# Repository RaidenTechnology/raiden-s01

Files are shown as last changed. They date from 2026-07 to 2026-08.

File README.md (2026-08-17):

# Raiden S0-1

**Open-hardware ESP32-S3 development board — designed from scratch in KiCad 9.**

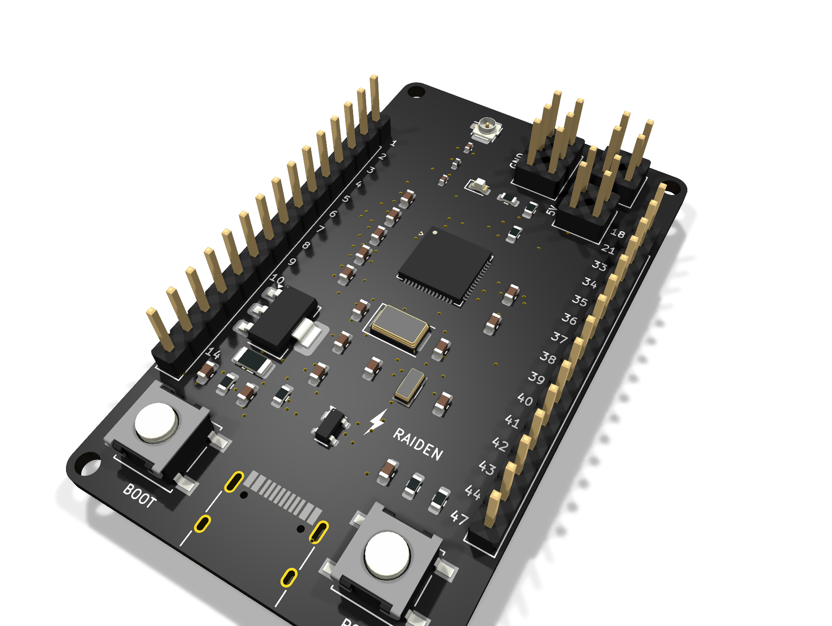
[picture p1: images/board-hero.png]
Raiden S0-1


## Overview

The Raiden S0-1 is a compact 4-layer devkit built around the **ESP32-S3FN8** (dual-core Xtensa LX7 @ 240 MHz, Wi-Fi + BLE 5, 8 MB embedded flash). Designed, routed and verified entirely by [Raiden Technology](https://github.com/RaidenTechnology).

| | |
|---|---|
| **MCU** | ESP32-S3FN8 (QFN-56, 8 MB flash) |
| **USB** | USB-C (USB 2.0), ESD-protected (PRTR5V0U2X), 5.1 kΩ CC pull-downs |
| **Power** | AZ1117C-3.3 LDO, 750 mA PTC resettable fuse, power LED |
| **RF** | U.FL (IPEX) antenna connector, feed line drawn for 50 Ω single-ended with a pi matching network — see the note below, impedance is **not** verified |
| **Clocks** | 40 MHz main crystal (CL = 8 pF) · 32.768 kHz RTC crystal (CL = 12.5 pF) |
| **I/O** | 2 × 15-pin 2.54 mm headers, BOOT + RESET buttons |
| **Board** | 4-layer FR-4, 1.6 mm — Sig / GND / +3V3 / Sig stackup, black soldermask |
| **Mounting** | 4 × M2 holes (NPTH) |

## Board views

| Top | Bottom |
|---|---|
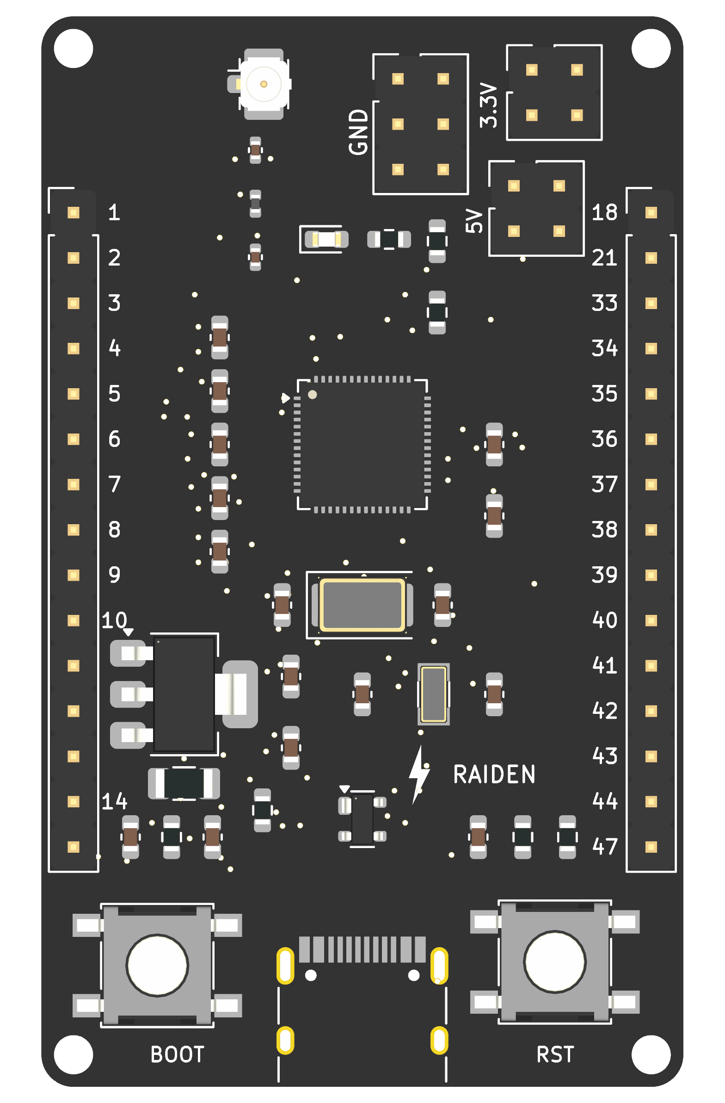
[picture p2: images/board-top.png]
Top
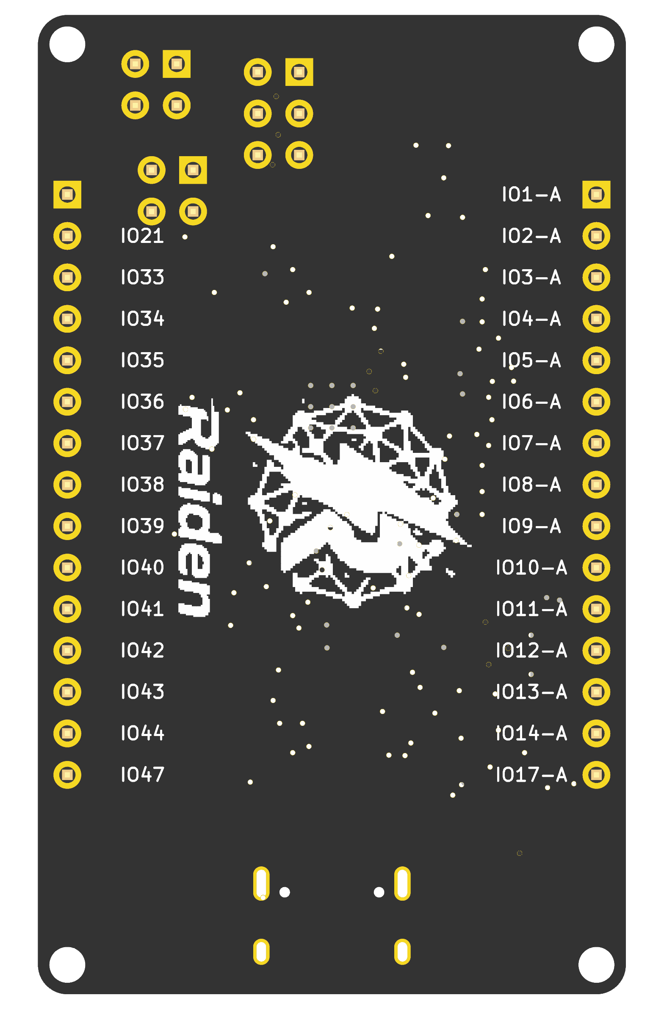
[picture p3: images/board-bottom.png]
Bottom
|  |  |

## Verification

- **ERC: 0 errors** — **DRC: 0 errors, 0 unconnected items** (KiCad 9.0.7, `kicad-cli`)
- 5 permanent DRC notices are intentional local footprint overrides (U.FL RF keepout + M2 mounting holes)

### Known limitations

- **The RF feed is not impedance-verified.** The trace is drawn at 0.2 mm and the design intent is 50 Ω single-ended, but no controlled-impedance stackup was ever defined for the project, so 50 Ω is an assumption rather than a calculated or measured figure. The pi matching network (1 pF / 2.0 nH / 1 pF) uses starting values with no VNA behind them and is expected to be tuned after measurement.
- **The board has not been manufactured.** The design is complete and the fabrication package is generated, but no production run has happened, so nothing here has been validated on real silicon.

## Repository layout

```
hardware/   KiCad 9 project (schematic, PCB, project file)
fab/        Production package: Gerbers (4-layer), drill files,
            BOM + CPL (JLCPCB format), pick-and-place, schematic PDF
images/     kicad-cli 3D renders
```

## Fabrication notes

Full notes in [`fab/README.txt`](fab/README.txt). Highlights:

- Standard 4-layer stackup (JLC7628 or equivalent)
- RF feed line routed for 50 Ω single-ended — ask your fab to adjust trace width to their stackup
- Via-in-pad under the SOT-223 regulator tab: plugged (IPC-4761 Type VI) or at least tented
- QFN-56 (0.4 mm pitch) — stencil and reflow profile matter
- Crystal load capacitance is board-matched: use CL = 8 pF for the 40 MHz crystal (C9/C10 = 10 pF)

## Status

Rev A — design complete and verification-clean; first fabrication run pending.

## License

Hardware licensed under **CERN-OHL-P v2** ([LICENSE](LICENSE)). Use it, modify it, build on it.

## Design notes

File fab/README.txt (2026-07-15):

RAIDEN S0-1 — ESP32-S3FN8 DEVKIT — Rev A — 2026-07-14
Raiden Technology
========================================================

ICERIK / CONTENTS
  Gerber\                        Gerber (11 katman) + Excellon delik (.drl) + delik haritasi
  Raiden S0-1 BOM.csv            Malzeme listesi (MPN'li, Value+MPN gruplu)
  Raiden S0-1 PickAndPlace.csv   Dizgi koordinat dosyasi (mm, ust+alt)
  Raiden S0-1 Schematic.pdf      Sema

URETIM NOTLARI / FABRICATION NOTES
  1. 4 katman / 4-layer, 1.6 mm FR-4.
     Stackup: F.Cu (sinyal) / In1.Cu = GND duzlemi / In2.Cu = +3.3V duzlemi / B.Cu (sinyal)
     JLC7628 veya esdegeri standart stackup uygundur.
  2. Soldermask: SIYAH / BLACK. Silkscreen: BEYAZ / WHITE (her iki yuz).
  3. KONTROLLU EMPEDANS / CONTROLLED IMPEDANCE:
     RF hatti LNA_IN -> ANT1 (F.Cu, 0.2 mm, kart ust bolgesi x~112) 50 ohm single-ended.
     Fab stackup'ina gore iz genisligi fab tarafindan ayarlanabilir / please adjust
     trace width to 50 ohm per your stackup, or advise required width.
  4. VIA-IN-PAD: U2 (SOT-223 regulator) tab pad'i altinda via (111.15, 138.75).
     Lutfen kapatin / plugged (IPC-4761 Type VI) veya en az tented.
  5. H1-H4: 4x M2 montaj deligi, NPTH (kaplamasiz) / non-plated.
  6. Min iz/bosluk / min track/clearance: 0.2 mm / 0.2 mm. Min delik / min drill: 0.3 mm.

DIZGI NOTLARI / ASSEMBLY NOTES
  - U1 = QFN-56 0.4 mm pitch, EP 4x4 mm — stencil ve refill profili onemli.
  - Y2 40 MHz kristal MUTLAKA CL = 8 pF olmali (C9/C10 = 10 pF buna gore secildi).
    Onerilen / suggested: ECS-400-8-30B-CKM.
  - Y1 32.768 kHz kristal CL = 12.5 pF (Epson FC-135; C11/C12 = 22 pF).
  - BOM'daki MPN'ler oneridir; stok/fiyat siparis oncesi dogrulanmali.

DOGRULAMA / VERIFICATION (KiCad 9.0.7, kicad-cli)
  ERC: 0 hata. DRC: 0 hata, 0 kopuk baglanti.
  (5 kalici uyari = kasitli yerel footprint kopyalari: ANT1 RF keepout + H1-H4.)

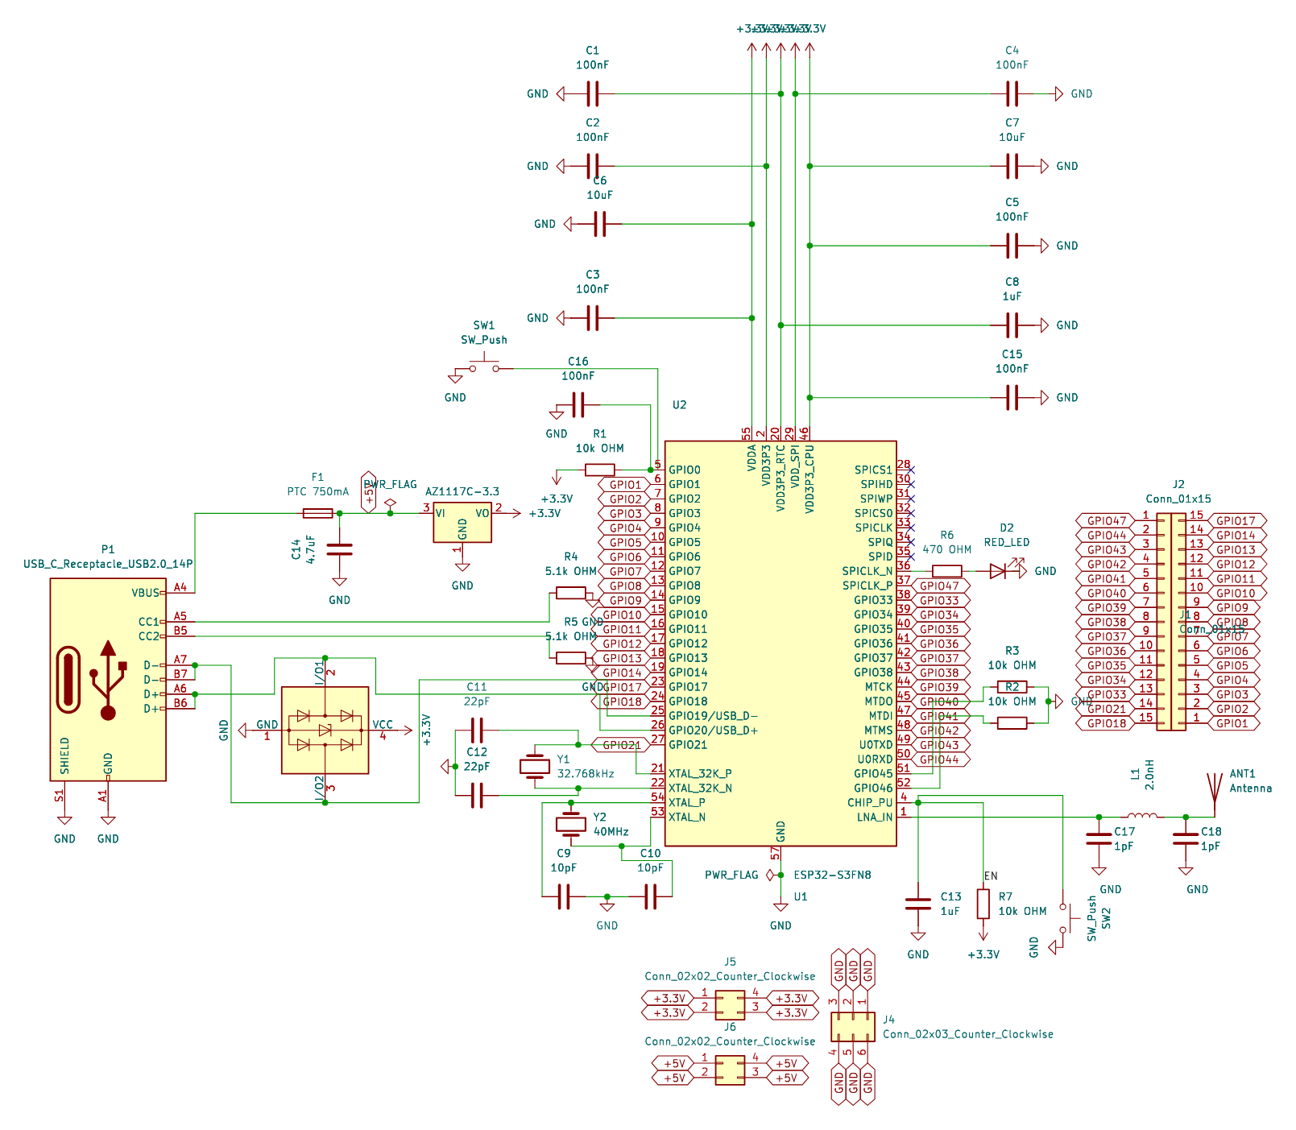
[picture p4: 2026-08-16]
images/schematic.png

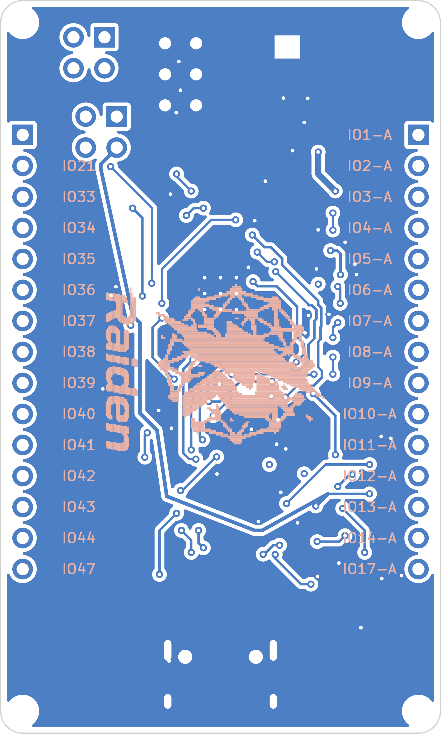
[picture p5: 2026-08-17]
images/pcb-back.png

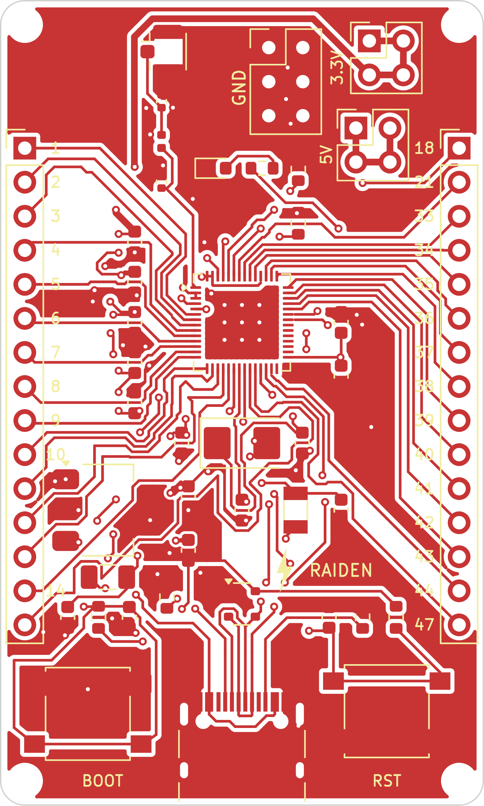
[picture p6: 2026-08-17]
images/pcb-front.png

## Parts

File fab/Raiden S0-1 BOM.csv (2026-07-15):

Reference | Value | MPN | Footprint
ANT1 | Antenna | U.FL-R-SMT-1(10) | Connector_Coaxial:U.FL_Hirose_U.FL-R-SMT-1_Vertical
C1-C5,C15,C16 | 100nF | CL10B104KB8NNNC | Capacitor_SMD:C_0603_1608Metric
C6,C7 | 10uF | CL10A106KP8NNNC | Capacitor_SMD:C_0603_1608Metric
C8,C13 | 1uF | CL10A105KB8NNNC | Capacitor_SMD:C_0603_1608Metric
C9,C10 | 10pF | CL10C100JB8NNNC | Capacitor_SMD:C_0603_1608Metric
C11,C12 | 22pF | CL10C220JB8NNNC | Capacitor_SMD:C_0603_1608Metric
C14 | 4.7uF | CL10A475KP8NNNC | Capacitor_SMD:C_0603_1608Metric
C17,C18 | 1pF | CL05C010BB5NNNC | Capacitor_SMD:C_0402_1005Metric
D1 | PRTR5V0U2X | PRTR5V0U2X,215 | Package_TO_SOT_SMD:SOT-143
D2 | RED_LED | KT-0603R | LED_SMD:LED_0603_1608Metric
F1 | PTC 750mA | 1206L075YR | Fuse:Fuse_1206_3216Metric
J1,J2 | Conn_01x15 |  | Connector_PinHeader_2.54mm:PinHeader_1x15_P2.54mm_Vertical
J4 | Conn_02x03_Counter_Clockwise |  | Connector_PinHeader_2.54mm:PinHeader_2x03_P2.54mm_Vertical
J5,J6 | Conn_02x02_Counter_Clockwise |  | Connector_PinHeader_2.54mm:PinHeader_2x02_P2.54mm_Vertical
L1 | 2.0nH | LQG15HS2N0S02D | Inductor_SMD:L_0402_1005Metric
P1 | USB_C_Receptacle_USB2.0_14P | TYPE-C-31-M-12 | Connector_USB:USB_C_Receptacle_HRO_TYPE-C-31-M-12
R1-R3,R7 | 10k OHM | 0603WAF1002T5E | Resistor_SMD:R_0603_1608Metric
R4,R5 | 5.1k OHM | 0603WAF5101T5E | Resistor_SMD:R_0603_1608Metric
R6 | 470 OHM | 0603WAF4700T5E | Resistor_SMD:R_0603_1608Metric
SW1,SW2 | SW_Push | B3S-1000 | Button_Switch_SMD:SW_SPST_B3S-1000
U1 | ESP32-S3FN8 | ESP32-S3FN8 | Package_DFN_QFN:QFN-56-1EP_7x7mm_P0.4mm_EP4x4mm
U2 | AZ1117C-3.3 | AZ1117CH-3.3TRG1 | Package_TO_SOT_SMD:SOT-223
Y1 | 32.768kHz | Q13FC1350000400 | Crystal:Crystal_SMD_3215-2Pin_3.2x1.5mm
Y2 | 40MHz | ECS-400-8-30B-CKM | Crystal:Crystal_SMD_5032-2Pin_5.0x3.2mm

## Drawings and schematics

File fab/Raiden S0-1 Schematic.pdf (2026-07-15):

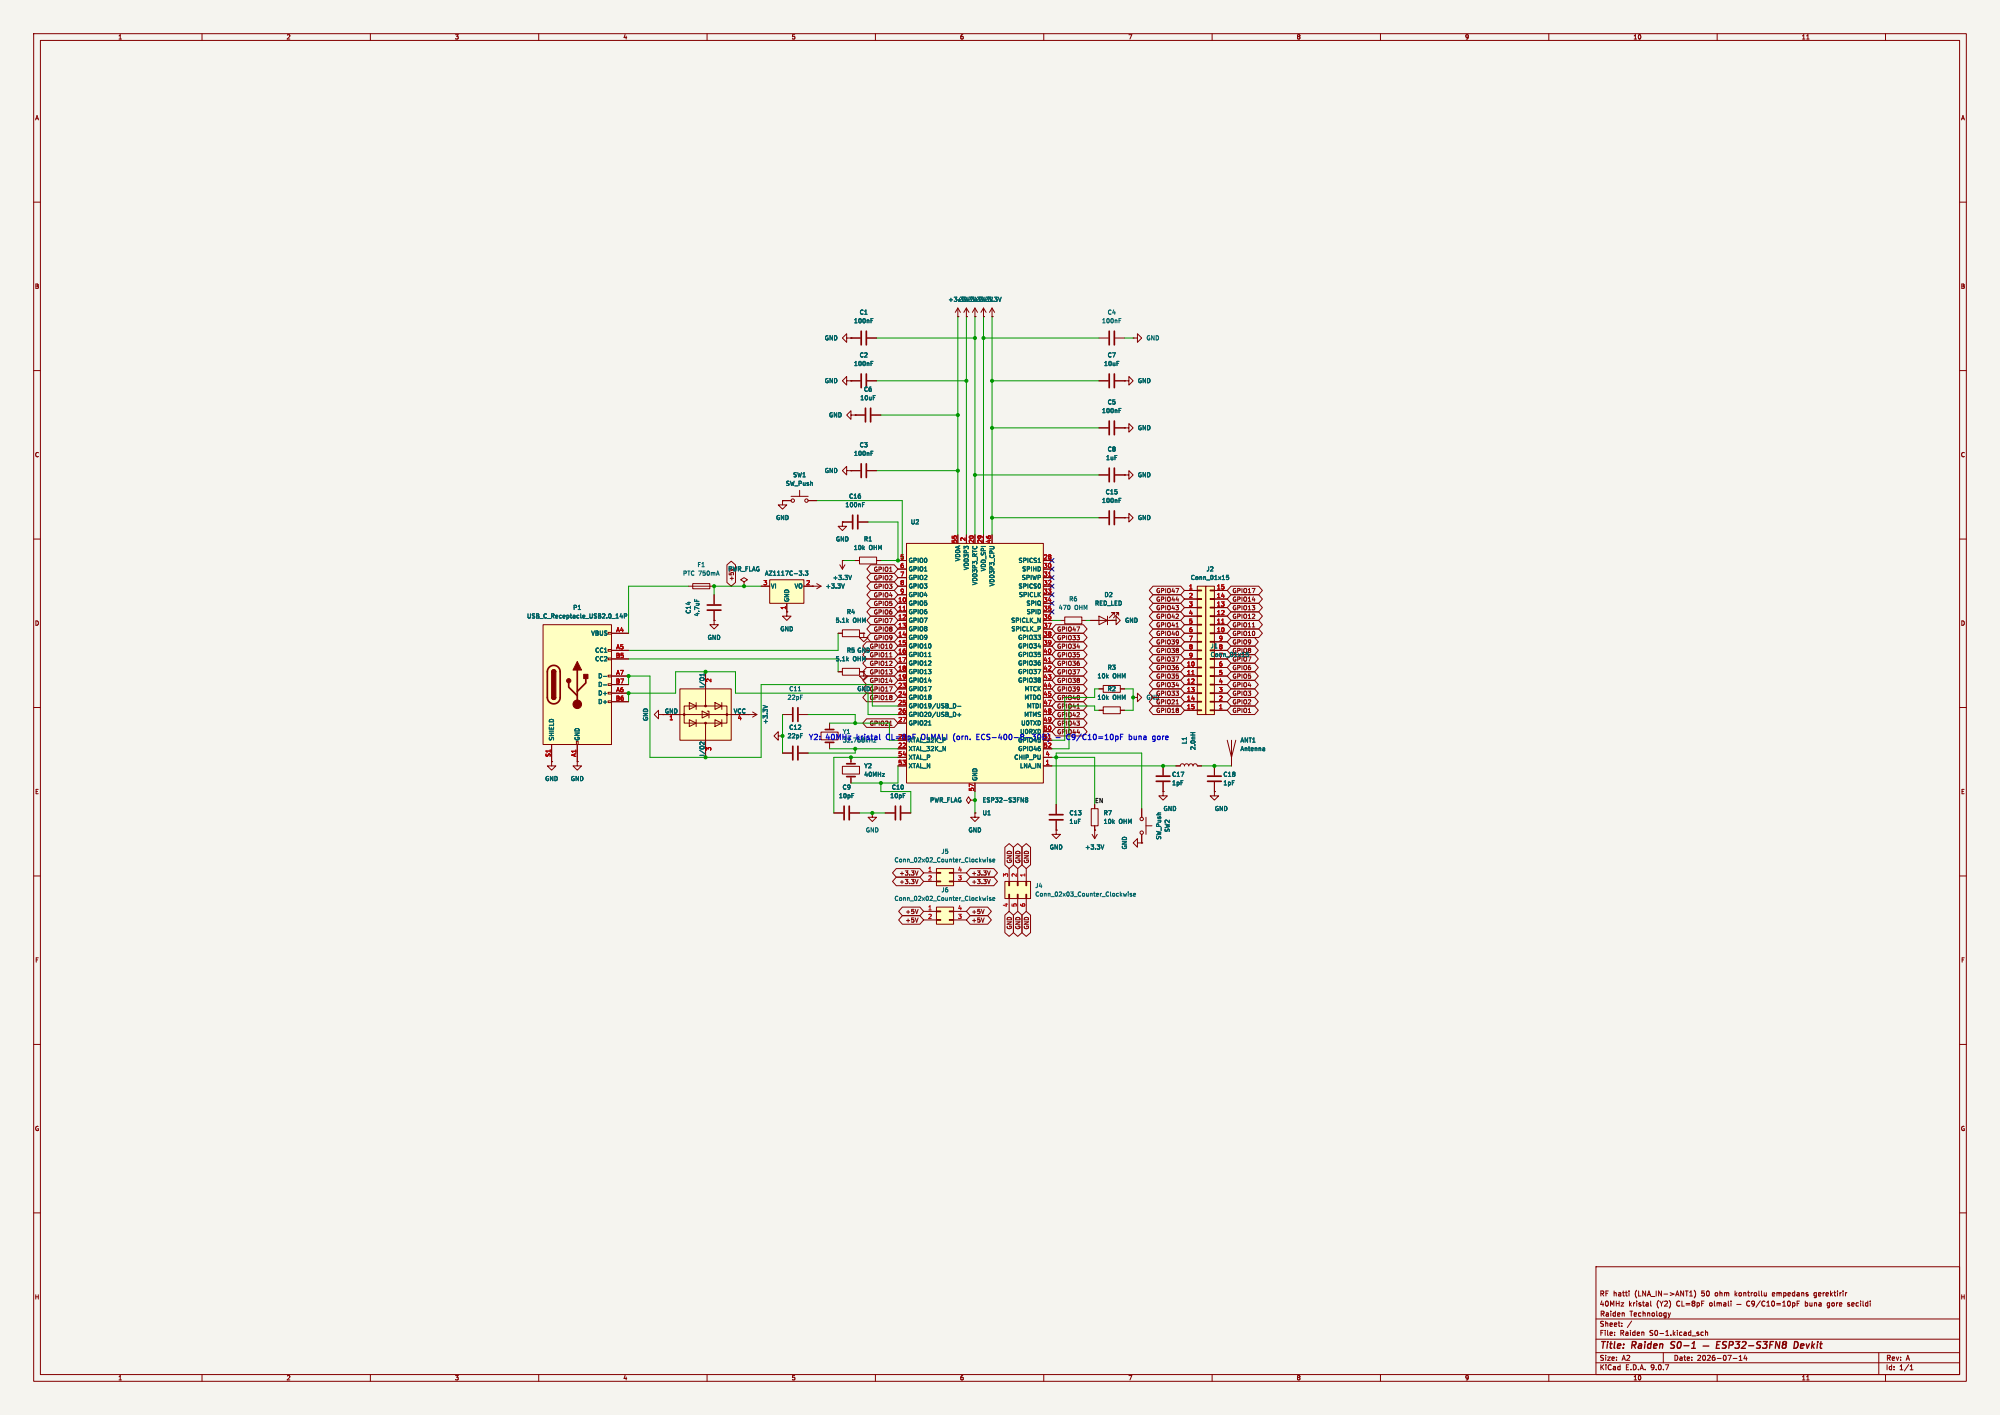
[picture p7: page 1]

2 VDD3P3_RTC 20 GND 57 VDD_SPI 29 VDD3P3_CPU 46 SPICS1 28 SPIHD 30 SPIWP 31 SPICS0 32 SPICLK 33 SPIQ 34 SPID 35 SPICLK_P 37 GPIO33 38 GPIO34 39 GPIO35 40 GPIO36 41 GPIO37 42 GPIO38 43 MTCK 44 MTDI 47 MTMS 48 U0TXD 49 U0RXD 50 GPIO46 52 CHIP_PU 4

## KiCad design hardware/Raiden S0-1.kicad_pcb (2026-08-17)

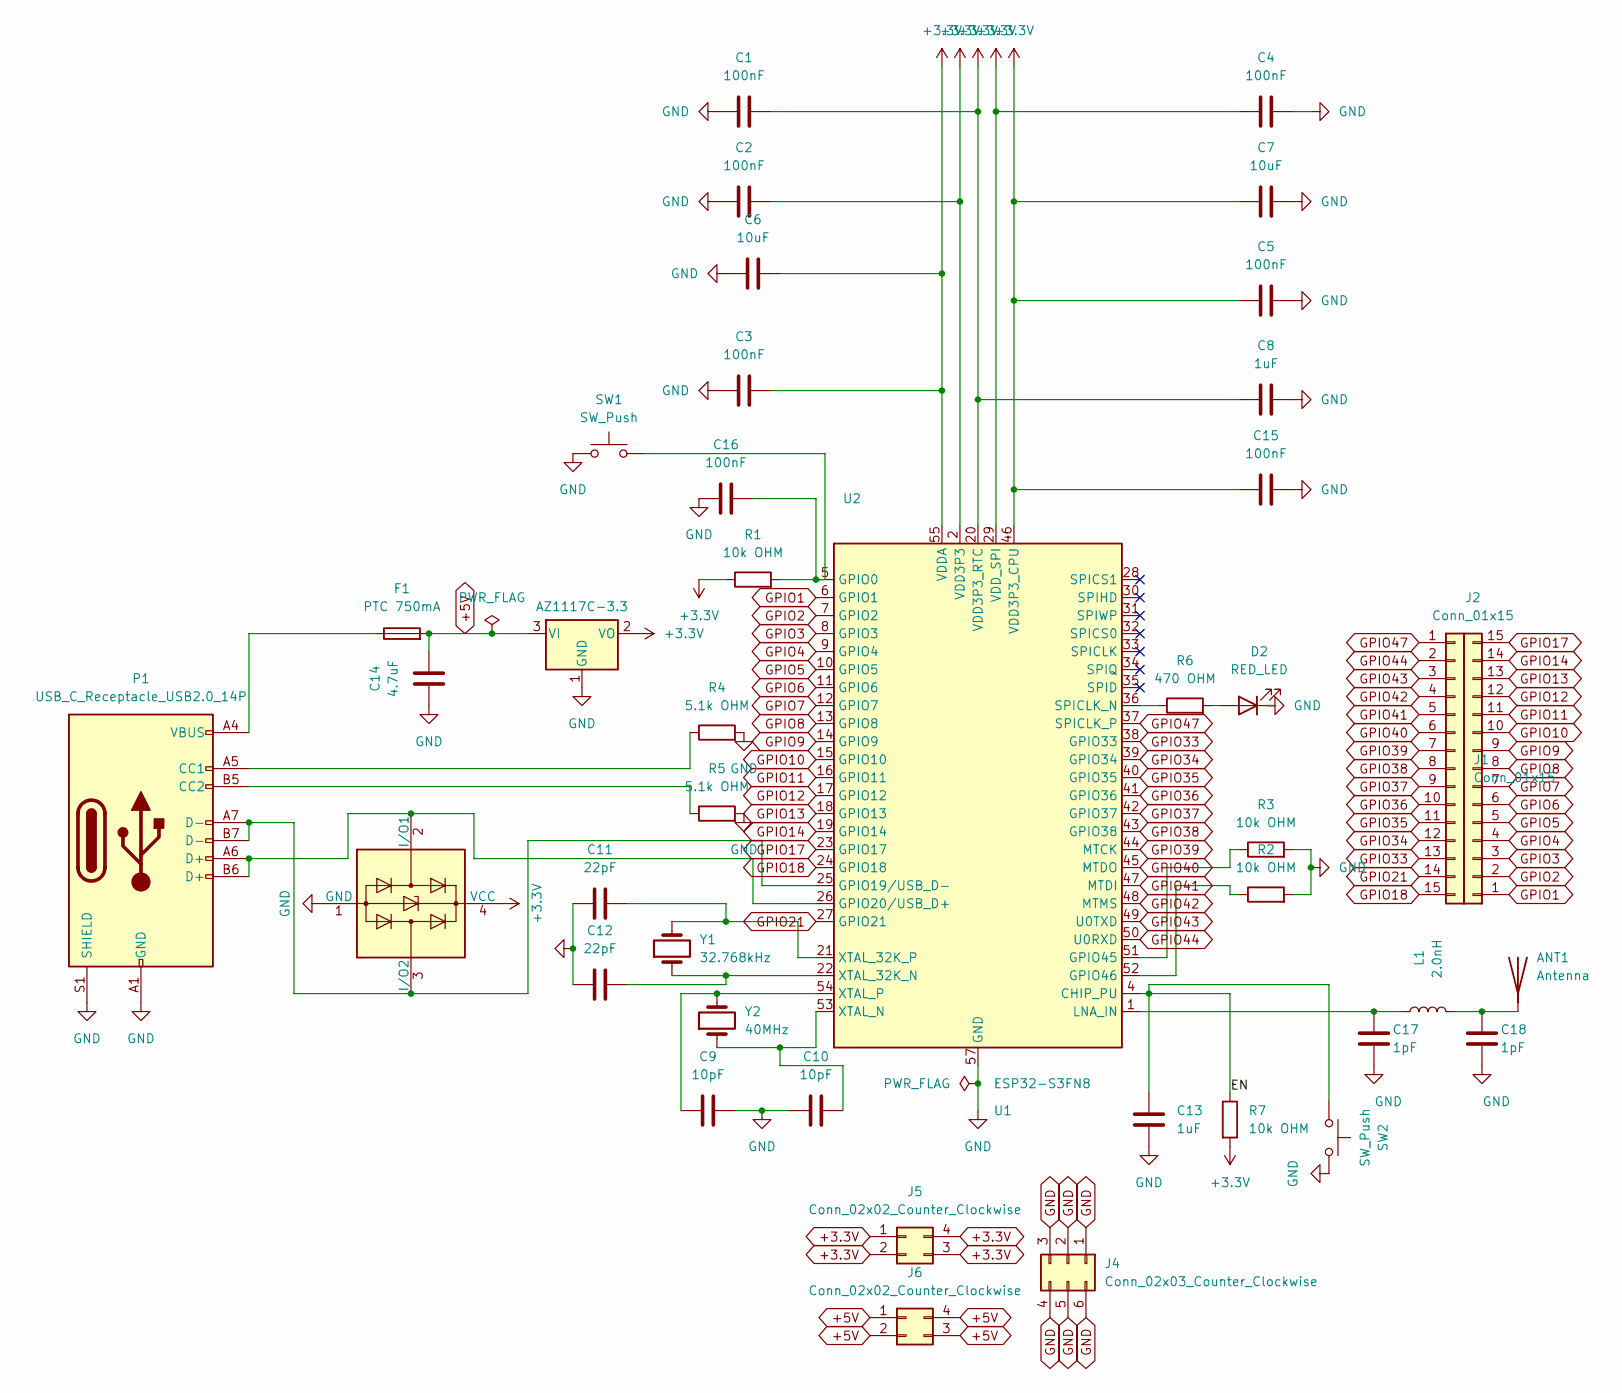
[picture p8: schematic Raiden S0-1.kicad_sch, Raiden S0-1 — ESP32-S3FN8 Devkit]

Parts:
ANT1: Antenna; U.FL_Hirose_U.FL-R-SMT-1_Vertical; MPN U.FL-R-SMT-1(10)
C1, C2, C3, C4, C5, C15, C16: 100nF; C_0603_1608Metric; MPN CL10B104KB8NNNC
C6, C7: 10uF; C_0603_1608Metric; MPN CL10A106KP8NNNC
C8, C13: 1uF; C_0603_1608Metric; MPN CL10A105KB8NNNC
C9, C10: 10pF; C_0603_1608Metric; MPN CL10C100JB8NNNC
C11, C12: 22pF; C_0603_1608Metric; MPN CL10C220JB8NNNC
C14: 4.7uF; C_0603_1608Metric; MPN CL10A475KP8NNNC
C17, C18: 1pF; C_0402_1005Metric; MPN CL05C010BB5NNNC
D1: PRTR5V0U2X; SOT-143; MPN PRTR5V0U2X,215
D2: RED_LED; LED_0603_1608Metric; MPN KT-0603R
F1: PTC 750mA; Fuse_1206_3216Metric; MPN 1206L075YR
J1, J2: Conn_01x15; PinHeader_1x15_P2.54mm_Vertical
J4: Conn_02x03_Counter_Clockwise; PinHeader_2x03_P2.54mm_Vertical
J5, J6: Conn_02x02_Counter_Clockwise; PinHeader_2x02_P2.54mm_Vertical
L1: 2.0nH; L_0402_1005Metric; MPN LQG15HS2N0S02D
P1: USB_C_Receptacle_USB2.0_14P; USB_C_Receptacle_HRO_TYPE-C-31-M-12; MPN TYPE-C-31-M-12
R1, R2, R3, R7: 10k OHM; R_0603_1608Metric; MPN 0603WAF1002T5E
R4, R5: 5.1k OHM; R_0603_1608Metric; MPN 0603WAF5101T5E
R6: 470 OHM; R_0603_1608Metric; MPN 0603WAF4700T5E
SW1, SW2: SW_Push; SW_SPST_B3S-1000; MPN B3S-1000
U1: ESP32-S3FN8; QFN-56-1EP_7x7mm_P0.4mm_EP4x4mm; MPN ESP32-S3FN8
U2: AZ1117C-3.3; SOT-223; MPN AZ1117CH-3.3TRG1
Y1: 32.768kHz; Crystal_SMD_3215-2Pin_3.2x1.5mm; MPN Q13FC1350000400
Y2: 40MHz; Crystal_SMD_5032-2Pin_5.0x3.2mm; MPN ECS-400-8-30B-CKM

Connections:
+3.3V: C1.2, C2.2, C3.2, C4.1, C5.1, C6.2, C7.1, C8.1, C15.1, D1.4 (VCC), J5.1, J5.2, J5.3, J5.4, R1.1, R7.2, U1.2 (VDD3P3), U1.3 (VDD3P3), U1.20 (VDD3P3_RTC), U1.29 (VDD_SPI), U1.46 (VDD3P3_CPU), U1.55 (VDDA), U1.56 (VDDA), U2.2 (VO), U2.4
+5V: C14.2, F1.2, J6.1, J6.2, J6.3, J6.4, U2.3 (VI)
/EN: C13.1, R7.1, SW2.1, U1.4 (CHIP_PU)
GND: ANT1.2, C1.1, C2.1, C3.1, C4.2, C5.2, C6.1, C7.2, C8.2, C9.1, C10.1, C11.1, C12.1, C13.2, C14.1, C15.2, C16.1, C17.2, C18.2, D1.1 (GND), D2.1 (K), J4.1, J4.2, J4.3, J4.4, J4.5, J4.6, P1.A1 (GND), P1.A12 (GND), P1.B1 (GND), P1.B12 (GND), P1.S1 (SHIELD), R2.2, R3.2, R4.2, R5.2, SW1.1, SW2.2, U1.57 (GND), U2.1 (GND)
GPIO1: J2.1, U1.6 (GPIO1)
GPIO2: J2.2, U1.7 (GPIO2)
GPIO3: J2.3, U1.8 (GPIO3)
GPIO4: J2.4, U1.9 (GPIO4)
GPIO5: J2.5, U1.10 (GPIO5)
GPIO6: J2.6, U1.11 (GPIO6)
GPIO7: J2.7, U1.12 (GPIO7)
GPIO8: J2.8, U1.13 (GPIO8)
GPIO9: J2.9, U1.14 (GPIO9)
GPIO10: J2.10, U1.15 (GPIO10)
GPIO11: J2.11, U1.16 (GPIO11)
GPIO12: J2.12, U1.17 (GPIO12)
GPIO13: J2.13, U1.18 (GPIO13)
GPIO14: J2.14, U1.19 (GPIO14)
GPIO17: J2.15, U1.23 (GPIO17)
GPIO18: J1.15, U1.24 (GPIO18)
GPIO21: J1.14, U1.27 (GPIO21)
GPIO33: J1.13, U1.38 (GPIO33)
GPIO34: J1.12, U1.39 (GPIO34)
GPIO35: J1.11, U1.40 (GPIO35)
GPIO36: J1.10, U1.41 (GPIO36)
GPIO37: J1.9, U1.42 (GPIO37)
GPIO38: J1.8, U1.43 (GPIO38)
GPIO39: J1.7, U1.44 (MTCK)
GPIO40: J1.6, U1.45 (MTDO)
GPIO41: J1.5, U1.47 (MTDI)
GPIO42: J1.4, U1.48 (MTMS)
GPIO43: J1.3, U1.49 (U0TXD)
GPIO44: J1.2, U1.50 (U0RXD)
GPIO47: J1.1, U1.37 (SPICLK_P)
unnamed: ANT1.1, C18.1, L1.2
unnamed: D1.2 (I/O1), P1.A6 (D+), P1.B6 (D+), U1.26 (GPIO20/USB_D+)
unnamed: D1.3 (I/O2), P1.A7 (D-), P1.B7 (D-), U1.25 (GPIO19/USB_D-)
unnamed: D2.2 (A), R6.2
unnamed: F1.1, P1.A4 (VBUS), P1.A9 (VBUS), P1.B4 (VBUS), P1.B9 (VBUS)
unnamed: P1.A5 (CC1), R4.1
unnamed: P1.B5 (CC2), R5.1
unnamed: C16.2, R1.2, SW1.2, U1.5 (GPIO0)
unnamed: R3.1, U1.51 (GPIO45)
unnamed: R2.1, U1.52 (GPIO46)
unnamed: C17.1, L1.1, U1.1 (LNA_IN)
unnamed: R6.1, U1.36 (SPICLK_N)
unnamed: C12.2, U1.22 (XTAL_32K_N), Y1.1
unnamed: C11.2, U1.21 (XTAL_32K_P), Y1.2
unnamed: C10.2, U1.53 (XTAL_N), Y2.1
unnamed: C9.2, U1.54 (XTAL_P), Y2.2

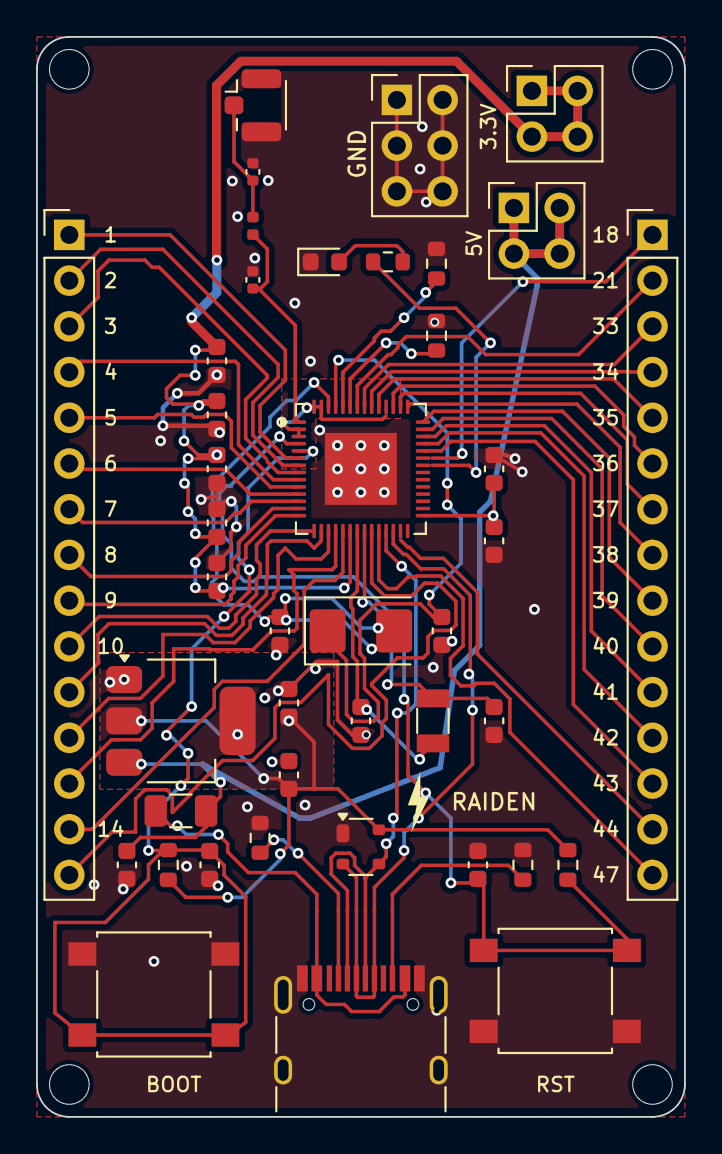
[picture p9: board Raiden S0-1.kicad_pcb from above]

Board: 4 copper layers, 36.0 x 60.0 mm, 46 parts (0 on the bottom side), 50 nets.

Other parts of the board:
H1, H2, H3, H4: MountingHole_M2; MountingHole_2.2mm_M2

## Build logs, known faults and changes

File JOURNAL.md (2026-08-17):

# Raiden S0-1 — Build Journal

**Project:** an open-hardware ESP32-S3 development board, designed from scratch in KiCad 9.
**Author:** Raiden Technology
**Repo:** https://github.com/RaidenTechnology/raiden-s01
**License:** CERN-OHL-P v2
**Total time:** ~60 hours across six sessions, 11–15 July 2026

> **A note on this journal, up front:** the design work happened over 11–15 July 2026. I
> published the repository as a single release commit on 15 July and only wrote this journal
> afterwards, from my own working notes. So the entries below are an honest reconstruction of
> real sessions, not a live log — I'd rather say that than pretend the commit history shows
> something it doesn't. Everything technical in here is verifiable against the files in
> `hardware/` and `fab/`.
>
> The same applies to images: I didn't capture screenshots while working, so the only renders
> I have are of the finished board, and they appear in the session where they were actually
> generated. I'd rather show three real images than dress up intermediate ones I never took.
> The full schematic is in [`fab/Raiden S0-1 Schematic.pdf`](fab/Raiden%20S0-1%20Schematic.pdf)
> and every claim below can be checked against the KiCad files in `hardware/`.

**What makes this board not "just another devboard":** it is built around a **bare ESP32-S3FN8
in a QFN-56 package**, not a pre-made module. That means the 0.4 mm pitch fanout, the crystal
network, the USB-C front end, the RF matching network and the 50 Ω antenna feed are all mine to
get right. It is also dual-purpose: standalone, or seated on a breadboard, with edge power rails
so sensors can be fed without a breadboard at all.

---

## Session 1 — 11 July 2026 · Schematic, and the first PCB layout
**Time:** ~14 hours

Built the schematic around the ESP32-S3FN8 (QFN-56, 8 MB embedded flash).

Design decisions made this session:
- **Regulator:** AZ1117-3.3 in SOT-223, switched away from an AP2112K. Bigger tab, better
  thermals for Wi-Fi bursts.
- **Protection:** 750 mA PTC resettable fuse in series with VBUS; PRTR5V0U2X ESD array shunting
  the USB D+/D− lines.
- **USB-C:** CC pull-downs, B6/A6 and B7/A7 bridged.
- **Reset / boot:** RC on CHIP_PU (10 kΩ + 1 µF) for the reset button, 100 nF debounce on the
  boot button.
- **Dropped the buzzer.** It was in the plan; it earned no space on the board.

**Trap I walked into:** the KiCad symbol names pins 36/37 "SPICLK_N" and "SPICLK_P", which reads
like they belong to the flash interface and are untouchable. They are not — on the FN8 they are
free GPIO48 and GPIO47. Only seven pins are genuinely off-limits (the internal flash: SPICS0/1,
SPICLK, SPIQ, SPID, SPIHD, SPIWP). I nearly threw away two usable I/O.

ERC reached 0. Added the RF chain (1 pF + 2.0 nH + 1 pF into a u.FL connector) with starting
values to be trimmed against a real measurement.

Laid out the PCB: 43 components on a 36 × 60 mm board, every footprint assigned.

**What I learned:** I tried to script the routing. On a 0.4 mm pitch QFN it produced shorts, and
I reverted the whole attempt. Hand routing it is — and the order matters: USB differential pair
first, then the 50 Ω RF feed, then power, then the crystal, then GPIO. The constrained,
irreversible things go first.

I also had both GPIO headers on the wrong sides relative to the chip's pin banks, so every
single signal was crossing the board to reach its header. Swapping them removed the problem
entirely. Cheap fix, but only because I caught it before routing.

---

## Session 2 — 12 July 2026 · Invisible disconnections, and why 2 layers wasn't enough
**Time:** ~13 hours

Checked the traces I had drawn by hand. Ten of them (GPIO1–8, 14, 17) **stopped 60–100 µm short
of the QFN pad copper.** On screen they looked connected. They were not. Several joints were
also 3–8 µm off-grid, which was quietly generating clearance violations.

**What I learned:** turn on magnetic pads, and always pull traces *outward from the chip* rather
than inward toward it. "It looks connected" is not a verification method — this is the single
most useful habit I picked up on this board.

Then I ran a union-find analysis over all the GND copper to see what was actually joined to
what. The result was unpleasant: **the bottom layer was not a ground plane at all.** It was
signal from top to bottom (3.3 V, EN, crystal, GPIO0, USB), with ground merely filling the
leftover gaps in three separate islands. The SMD capacitors' ground pads couldn't reach it —
there were no vias. I added 7 GND vias, each one geometry-checked (inside the GND polygon,
≥ 0.2 mm from any signal, actually connected to the main island). Disconnected GND nodes went
19 → 12.

I tried to solve the +3.3 V distribution with a copper zone on the front layer. **Zero polygons
filled.** The area around the chip is so dense with header fanout that not even a 0.25 mm pour
fits. That failure was the useful part: it was proof, not opinion, that the board needed more
layers.

**Moved to 4 layers:** inner layer 1 = full ground plane, inner layer 2 = full +3.3 V plane.

**What I learned (the part I had wrong):** going to 4 layers gives you power and ground planes,
but the *signal* layer count is still two. The congestion around the QFN does not improve at
all. I expected the extra layers to relieve the fanout; they didn't. What they fixed was
distribution, not routing.

Two tooling lessons from this session:
- `kicad-cli` **does not refill zones.** It validates against the last saved fill, so any new
  zone connection reads as broken until refilled in the GUI. I chased phantom errors before
  I understood this.
- When editing the board file as text, the zone anchor must be matched as a newline + single
  tab. Matching a bare tab hits the keepout zone *inside a footprint* instead and corrupts the
  file. I did this, and had to revert.

---

## Session 3 — 12–13 July 2026 · Hunting isolated copper, and blind vias
**Time:** ~11 hours

`kicad-cli` DRC kept reporting the ground zone as having a missing connection, but the
coordinates it gave were useless — it always points at the zone anchor, not the actual fault.

I wrote a proper check instead: union-find across *all* ground copper on all layers, joining
vias, pads and tracks by **shape collision** rather than by centre point. A centre-point test
gives wrong answers, because two shapes can overlap without either centre being inside the
other.

That found the real faults: three genuinely isolated pockets of front-layer ground.

Two of them sat directly over congested bottom-layer copper. Dropping a normal through via there
would have **shorted ground into the EN and 32 kHz crystal traces.** So I used blind vias, front
layer down to the inner ground plane only.

Then I undid that. **Standard 4-layer fabrication cannot do blind vias** — it's a sequential
lamination process and costs multiples of a plain board. I converted both back to through vias
and moved them to points I searched for programmatically: somewhere that a via *and* its
connecting stub would both clear every existing track, via and pad.

**What I learned:** design for the process, not just for the tool. KiCad let me draw something
that no affordable fab would build. That distinction was invisible to me until I went looking
for the price.

Also caught this session: **the regulator's thermal tab pad had no net assigned — it was
floating.** The part would have worked and then cooked. Assigned it to +3.3 V, added a thermal
via and a local zone.

---

## Session 4 — 13 July 2026 · Cleanup and optimisation
**Time:** ~8 hours

- Added 4 × M2 mounting holes (non-plated), positioned by searching the corners for spots that
  didn't collide with the boot button or the regulator cluster.
- **Silkscreen: 32 violations → 0.** Pulled the header pin numbers inward, shifted the rear I/O
  name column. Four labels had to be deleted outright — the gap between one header pad and the
  regulator cluster is 0.46 mm, and no legible text fits in that. The rear-side I/O names and
  the neighbouring front numbers make up for it.
- **+5 V route: 61 segments → 12**, by string-pulling the path against the real obstacle set.
  It had been an ugly zigzag left over from an automated attempt.
- Added 5 ground stitching vias along the RF feed line.

**What I learned:** my via-placement checker validated against tracks, pads and vias — but it
knew nothing about **keepout zones**, so it happily placed a via inside the u.FL antenna
keepout. The keepout under the antenna is deliberate: it's an intentional gap in the copper, and
it is *not* a mistake to be filled in. I had to exclude the RF region by hand. A checker is only
as good as the constraint list you gave it, and the constraints you forget are invisible.

---

## Session 5 — 14 July 2026 · Reviewing my own board
**Time:** ~6 hours

Went through the board as if reviewing someone else's work, against a checklist. Scored it
**84/100** and wrote down the deductions honestly rather than defending the design.

Fixed:
- Deleted a dangling 3.3 V trace stub.
- Added title blocks to both schematic and board (name, revision, date, crystal and impedance
  notes).
- Added **manufacturer part numbers to 37 components** — until then the BOM was unbuildable by
  anyone but me.
- Put a visible "CL = 8 pF" warning on the schematic canvas next to the 40 MHz crystal. The
  board's 10 pF load capacitors only give the right oscillator load for an 8 pF crystal; buying
  the wrong one produces a board that looks fine and won't boot.
- Added three fabrication notes to the board comments layer.
- Generated the BOM.

Then I verified that the netlist was **node-for-node identical** to before. Adding metadata
should change nothing electrically, and I wanted that proven rather than assumed.

**Known weaknesses I did not fix, and am not hiding:**
- No Schottky diode between the 5 V rail and USB VBUS — if the board is powered from both at
  once, there's a back-feed path.
- The 100 nF decoupling capacitors sit 4.5–6 mm from the chip's power pins. That's further than
  I want; it's a consequence of the fanout congestion.
- The RF feed is drawn for 50 Ω but **not impedance-verified** against a defined stackup. The
  fab notes ask the manufacturer to adjust trace width to their actual stackup.

These are Rev B work, along with a power LED and tighter decoupling.

---

## Session 6 — 14–15 July 2026 · Fabrication package and release
**Time:** ~8 hours

Filled all six zones through the pcbnew Python API, because `kicad-cli` has no fill command at
all — this was the last piece of the "why do my zone errors never clear" puzzle from Session 2.

Exported the full production package into `fab/`: 11 Gerber layers, Excellon drill files, a
drill map, pick-and-place data, the schematic as PDF, and the BOM with part numbers. (Small
trap: the drill export takes `--excellon-units`, not `--units`. The generic flag is silently
wrong.)

Rendered three views with `kicad-cli pcb render`. These are the board as it stands today —
what the grant would turn into copper:

**Top** — the QFN-56 in the centre, both 15-pin GPIO headers, USB-C at the edge, the u.FL
antenna connector and its deliberate copper keepout, and the silkscreen after the cleanup pass
in Session 4 (pin numbers on the front, I/O names on the back):

Top view

**Bottom** — the rear I/O name column, the edge power rails, and the four M2 mounting holes:

Bottom view

**Perspective:**

Hero render

(A render trap worth noting: `--rotate` needs its value in nested quotes, e.g.
`--rotate "'-35,0,-30'"`, or the argument parser rejects it.)

Published the repository under CERN-OHL-P v2.

**Final verification state:** ERC 0 errors · DRC 0 errors · 0 unconnected items. Five remaining
DRC notices are intentional local footprint overrides — the u.FL RF keepout and the four
mounting holes — and they are documented as such rather than suppressed.

---

## Session 7 — 17 August 2026 · Review feedback, and a connector that could never have been plugged in

I submitted this board to a build grant, and a reviewer looked at the renders and said the USB-C
port should be at the edge of the board, otherwise you won't be able to reach it.

He was right, and it was not a cosmetic point. I measured it: the connector body ended at
y = 156.25 mm and the board edge is at y = 160 mm, so **3.75 mm of solid PCB sat directly in
front of the connector opening**. A cable's overmould would have hit the board before the plug
seated. Five people had by then been pointed at this repository, and nobody had caught it,
because the board looks completely normal until you think about the third dimension.

Moving the connector turned out not to be a drag-and-drop. USB-C is reversible, so VBUS appears
on two pads and D+ on two more, and those pairs are bridged by a small fan-out structure routed
*underneath* the connector. My first attempt moved the connector and extended the eight traces
that feed it from above, but left the bridges where they were — which drew CC2 straight across a
VBUS trace and shorted them. DRC caught it immediately. The fix was to recognise that the bridge
belongs to the connector, not to the board, and translate the whole assembly together. Notably
the original bridge routing threads between the connector's own NPTH mounting posts, and moving
it as one piece preserved that automatically.

One extension was also wrong: I had generated a stub for every trace endpoint touching a pad,
but the right-hand VBUS pad is fed only by the bridge, never from above. That produced a 3.75 mm
trace hanging in mid-air. DRC reported it as an unconnected end and I deleted it.

The other three review points:

- **Rounded corners.** The outline was a plain rectangle. I set the radius to 1.8 mm, which is
  exactly the mounting-hole inset, so each corner arc is concentric with its hole and the web
  between hole and board edge stays 0.70 mm the whole way round — the same as it was with square
  corners. Both a larger and a smaller radius make that web thinner, which is a pleasing result:
  the geometry picks its own answer.
- **The odd mounting hole.** Three holes sat 1.8 mm in from their edges and the fourth sat 4.6 mm
  in, because the BOOT button occupied that corner. Moving the button up 0.3 mm cleared it, and
  the hole went to 1.8 mm like the others. The button's ground pads carry no traces at all — they
  are fed by the plane — so only four segments had to follow it.
- **Silkscreen art.** The front had no board identity at all. A free-space scan over courtyards,
  pads and existing silk found exactly one usable gap on the whole board, 12 x 4 mm, and a
  lightning bolt and the word RAIDEN now live in it. My first attempt collided with a pin number;
  the scan had missed it because my parser choked on nested `effects` blocks in the text
  elements. DRC's silkscreen-overlap check caught what my own tool had missed.

**Verification state after the revision:** ERC 0 errors · DRC 0 errors · 0 unconnected items ·
0 schematic-parity issues. The fabrication package, placement files and renders were all
regenerated from the revised board, because a repository that ships stale Gerbers alongside a
corrected board is worse than one that ships nothing.

The lesson worth keeping: this was caught by someone glancing at pictures, days before any money
was spent. Every automated check I own passed on a board that could not have been plugged in.

---

## Status

**Rev A is design-complete and verification-clean, and has never been manufactured.** The
Gerbers in `fab/` have not yet been sent to a fab. That first run is exactly what I'm asking a
build grant to cover. As of 17 August 2026 the board carries the four fixes from Session 7 —
the USB-C connector now reaches the board edge, the corners are rounded, the mounting holes are
evenly inset and the front carries a brand mark.

**Rev B** is in progress in a separate project: the same board with the GPIO headers spaced
25.4 mm apart so it seats on a breadboard and stays pin-compatible with a DevKitC. Two nets
still need routing there.

## What I'd tell someone starting a board like this

1. **Verify, don't look.** Ten of my traces were disconnected by 60 µm and looked perfect.
2. **Automate the checking, hand-route the copper.** Every routing script I wrote on 0.4 mm
   pitch produced shorts. Every *analysis* script I wrote found real faults I'd never have
   spotted by eye.
3. **A tool letting you draw it doesn't mean a factory can build it.** Blind vias taught me that.
4. **When something fails to fit, that's data.** The zone that filled zero polygons is what told
   me the board had to go to four layers.

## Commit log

2026-07-15 Raiden S0-1 Rev A — ESP32-S3FN8 devkit, ERC/DRC clean, fab package included
    [Raiden S0-1 BOM.csv, Raiden S0-1 BOM_JLC.csv, Raiden S0-1 PickAndPlace.csv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]
2026-08-16 Add build journal documenting the Rev A design sessions
    Six sessions covering schematic, the move to 4 layers, isolated-copper
    analysis, blind-via rework, self-review and the fab package. Time fields
    left blank pending the author's own figures.
2026-08-16 Add board renders to the journal, note the screenshot gap honestly
2026-08-16 Add schematic and PCB layout renders
    Generated with kicad-cli SVG export; front view shows F.Cu over B.Cu with
    silkscreen, back view the reverse. Inner planes omitted so routing stays visible.
2026-08-16 Remove the Turkish crystal note from the schematic canvas
    It overlapped the 32.768 kHz crystal label and was the only non-English text
    on the sheet. The CL = 8 pF requirement is still recorded in README.md, the
    BOM part number and fab/README.txt. ERC 0 violations; netlist verified
    node-for-node identical.
    [Raiden S0-1.kicad_sch]
2026-08-16 Fill in session times — ~60 hours total
2026-08-17 Stop claiming controlled impedance on the RF feed
    The spec table said "50 ohm controlled-impedance feed line". No
    controlled-impedance stackup was ever defined for this project, so 50 ohm
    is design intent, not a verified figure. JOURNAL.md already said this;
    the README did not.
    Adds a Known limitations section covering both the unverified RF feed and
    the fact that the board has not been manufactured yet.
2026-08-17 Rev A2: move USB-C to the board edge, plus review fixes
    A build-grant reviewer pointed out from the renders that the USB-C port
    does not reach the edge of the board. Measured: the connector body ended
    3.75 mm short of the edge, so a cable would have hit the PCB before the
    plug seated. The board could not have been used.
    - USB-C moved down so its face lands on the board edge. The VBUS and D+
    pads are bridged underneath the connector for reversibility; that
    fan-out had to travel with it. Moving the connector alone shorted CC2
    to VBUS, which DRC caught.
    - Corners rounded at R = 1.8 mm, equal to the mounting-hole inset, so the
    arcs are concentric with the holes and the web between hole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
    [Raiden S0-1 PickAndPlace.csv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]
